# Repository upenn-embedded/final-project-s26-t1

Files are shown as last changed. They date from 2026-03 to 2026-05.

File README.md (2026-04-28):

Review Assignment Due Date (https://classroom.github.com/a/-Acvnhrq)

# Final Project

**Team Number:** 1

**Team Name:** Virtual Etch-a-Sketch

| Team Member Name | Email Address |
| --- | --- |
| Cameron Shaw | cshaw1@seas.upenn.edu |
| Clayton Hickey | clhickey@seas.upenn.edu |
| Elan Goldman | elangol@seas.upenn.edu  |

**GitHub Repository URL:** https://github.com/upenn-embedded/final-project-s26-t1

**GitHub Pages Website URL:** https://upenn-embedded.github.io/final-project-s26-t1/

## Final Project Proposal

### 1. Abstract

A device with a large tri-color e-ink display and knobs that will behave like an Etch-a-sketch, a mechanical 2D plotter toy that draws lines on its screen. Our project will reimagine the experience of using an etch-a-sketch while keeping the shake to erase functionality and classic 2 knobs for controlling the drawing cursor. The virtual etch-a-sketch will also have USB support, so that the knobs can be used to create drawings in apps like MS Paint or GIMP.

### 2. Motivation

The goal of this project is to expand what an etch-a-sketch can be while also reducing the durability issues that arise from the completely mechanical design of the original. The etch-a-sketch was originally designed to be a toy, while the virtual etch-a-sketch is targeted at artists who want a more consistent experience and more ways to augment the etch-a-sketch medium.

### 3. System Block Diagram

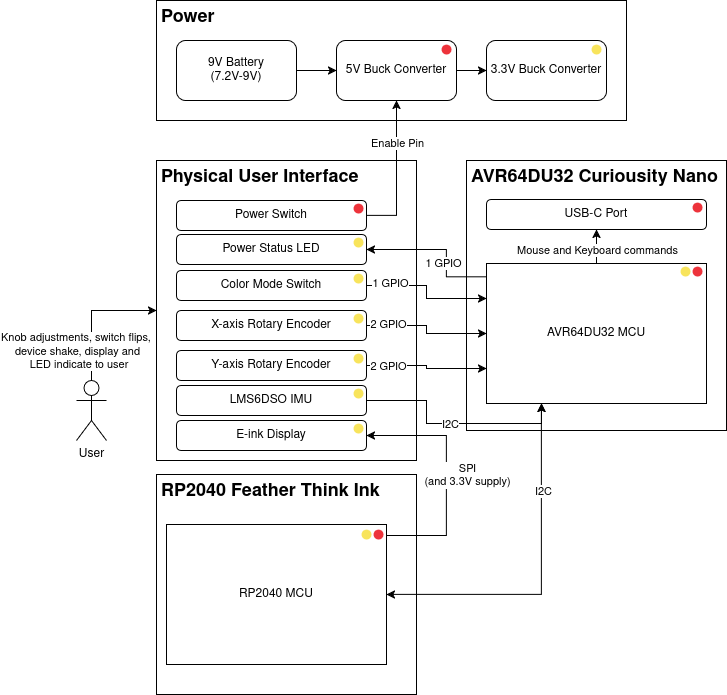
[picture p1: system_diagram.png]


**Key**

Red: Regulated 5V

Yellow: Regulated 3.3V

### 4. Design Sketches

We will 3D print the entire enclosure and knobs for the etch-a-sketch. We will need a soldering iron for making electrical connections, as well as adding heat set inserts if needed.

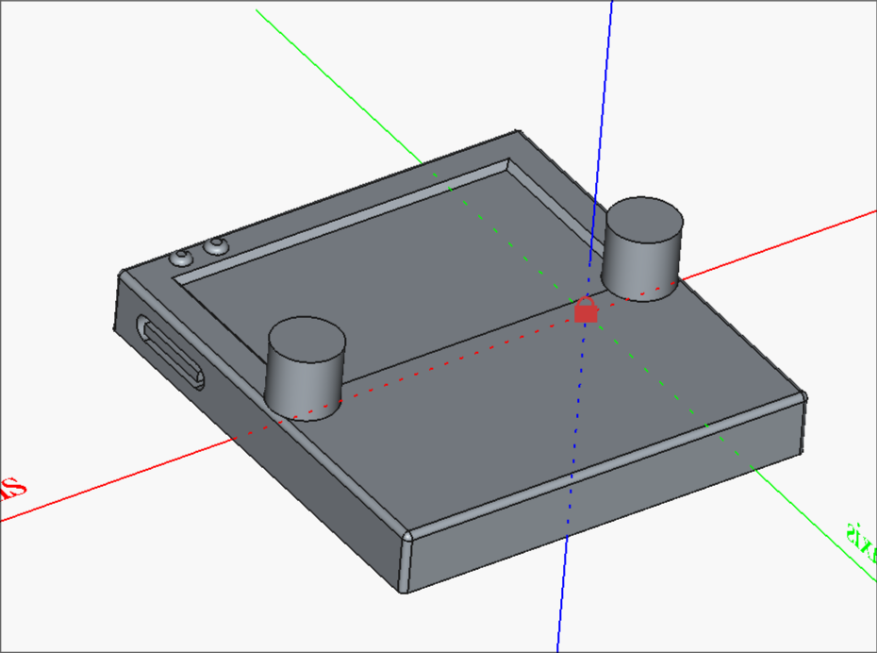
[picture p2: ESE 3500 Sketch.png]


### 5. Software Requirements Specification (SRS)

**5.2 Functionality**

| ID | Description |
| :--- | :--- |
| **SRS-01** | The device shall display and persist user-drawn lines on the display. The cursor shall remain at the boundary of the screen if a user attempts to move it beyond the display coordinates. |
| **SRS-02** | The system shall update the cursor position based on simultaneous inputs from both knobs to do diagonal and curved line rendering. |
| **SRS-03** | The system shall respond to knob rotations with a display latency of less than 100 milliseconds to ensure real-time user interaction. |
| **SRS-04** | Upon USB connection to a host PC, the device shall enumerate as a Human Interface Device (HID) and map knob rotations to mouse-drag and click events. |
| **SRS-05** | The system shall monitor the IMU and trigger a screen-clear event only when a continuous shaking motion is detected for a duration exceeding 1 second. |
| **SRS-06** | The system shall change the active drawing color between black and red upon a toggle of the color mode switch, while maintaining the color of previously drawn lines. |

### 6. Hardware Requirements Specification (HRS)

**6.1 Definitions, Abbreviations**

- **USB:** Universal Serial Bus
- **PC:** Personal Computer
- **HID:** Human Interface Device
- **IMU:** Inertial Measurement Unit

**6.2 Functionality**

| ID | Description |
| :--- | :--- |
| **HRS-01** | The device shall be powered by a 9V Alkaline battery and maintain operation for a minimum of 10 minutes under continuous use. |
| **HRS-02** | The power management circuit shall maintain uninterrupted system operation during the transition of plugging or unplugging a USB-C cable. |
| **HRS-03** | A physical power switch shall be integrated to disconnect the battery from all downstream circuitry, resulting in zero current draw (excluding ambient battery discharge). |
| **HRS-04** | The device enclosure shall feature two knobs positioned at the bottom corners of the display to emulate a mechanical drawing toy. |
| **HRS-05** | The rotary encoders used for knobs shall be non-detented to provide smooth, continuous rotation without tactile clicks or bumps. |
| **HRS-06** | The device chassis and internal component mounting shall withstand shaking without loss of electrical connectivity or functional failure. |

_Note: we used Gemini to format the requirements._

### 7. Bill of Materials (BOM)

https://docs.google.com/spreadsheets/d/18jHvc1XVHpzNt5ybeaLdjjYaHa1GXTPeQhFLGrUgIds/edit?usp=sharing

**AVR64DU32 Curiosity Nano**: This is the main MCU where we will run our bare metal C code. This MCU is responsible for user input, sending drawing commands to the E-Ink MCU, and interfacing with a connected laptop over USB. We chose this board over the Atmega328PB dev board because it has a USB 2.0 interface that we can use to have it act as a keyboard and/or mouse on the connected laptop.
**Rotary Encoder**: We will have two rotary encoders, just as an etch-a-sketch would, one for controlling the x-axis and one for the y-axis. We chose rotary encoders because they allow for many turns in each direction unlike a normal potentiometer and can be read using regular GPIO thanks to their digital output.
**eInk Display**: This is the display of the etch-a-sketch. We chose a large 7.5” display to approximate the dimensions of a full size etch-a-sketch. The eInk display gives the device a look closer to an real etch-a-sketch. The model can also display red pixels, and we will take advantage of this by including a color mode switch.
**IMU Breakout Board**: The IMU will be responsible for detecting when the user shakes the device to clear its screen. We chose this IMU because it is the same as the one used in WS3.
**RP2040 Feather ThinkInk**: This the secondary MCU used to control the eInk display. Because the eInk display requires a full refresh when updating it, we need a separate MCU with enough RAM to store the display state. We chose this board because it is designed for this exact purpose and includes the 24-pin connector that the eInk display uses.
**3.3V/5V Buck Converters**: As shown in the system diagram, we will need 3.3V for most devices on the board, though some require a higher supply voltage for their onboard regulators, hence why we also need a 5V buck converter. The buck converter boards we chose from Sparkfun provide a sufficient amount of current and feature an enable pin that our power switch could use.
**9V Battery Hat + Battery**: We want the device to function wirelessly, so we chose to use a 9V due to the University’s safety requirements. The battery holder will provide 7.2-9V, which is sufficient for the 5V and 3.3V converters.

### 8. Final Demo Goals

The device is battery powered, so it’s sufficient to just have some table space for the device to sit and a connected laptop to demonstrate the additional features of the virtual etch-a-sketch. We should bring an extra battery just in case.

### 9. Sprint Planning

| Milestone  | Functionality Achieved | Distribution of Work |
| --- | --- | --- |
| Sprint #1  | The display turns on and can be drawn to. The USB HID on the Curiousity Nano functions on its own. A preliminary version of the enclosure has been designed. | We will split this work based on our availabilities by meeting before the sprint start. |
| Sprint #2  | The display can be drawn to by the knobs, though some functionality or latency issues may be present. The Curiousity Nano USB HID functions as a mouse using control from the knobs separately. A physical enclosure draft has been printed and components have been test fitted. | We will split this work based on our availabilities by meeting before the sprint starts. |
| MVP Demo | We put all the components in the enclosure and the HID and display programs have been merged so they work simulatenously. The color mode and shake detection has also been added at this point. | We will split this work based on our availabilities by meeting before starting this phase. |
| Final Demo | We satisfy all our required system requirements. | We will split this work based on our availabilities by meeting before starting this phase. |

**This is the end of the Project Proposal section. The remaining sections will be filled out based on the milestone schedule.**

## Sprint Review #1

### Last week's progress

- Ordered parts from Mouser and Amazon as well as the eInk display from Crowd Supply.
- Wrote code for and successfully tested a simple etch-a-sketch using Lab 4 parts. We don't plan on using the Lab 4 display due to its small size or the joystick for it, but this gives us a starting point while we wait for parts to arrive.
- Set up AVR64DU32 in MPLAB X IDE. We have tested USB HID functionality using Microchip's demo.
- Wrote a simple program using Microchip Code Configurator for the AVR64DU32 to test I2C communication with the IMU.
- Acquired a Raspberry Pi 4B with 6" touchscreen display from Detkin staff.
- Set up reproducible RPI image using NixOS. It boots but the screen doesn't work yet.

### Current state of project

- Etch-a-sketch proof of concept using Lab 4 joystick and display
- Working USB HID and I2C on the AVR64DU32 Curiousity Nano
- RPI for driving display is working but only insofar as it boots

### Next week's plan

- Port proof of concept from ATMega328PB to AVR64DU32
- Add shake detection using IMU with AVR64DU32
- Get RPI image working with display
- Replace joystick with rotary encoder dials (assuming they arrive before the end of the week)

## Sprint Review #2

### Last week's progress

- Wrote I2C driver (instead of using MCC generated one) with non-blocking read/write transactions
- USB HID with keyboard and mouse (previously was just keyboard) on AVR64DU32
- Determined we can use Wake Up event on LSM6DSO IMU for shake detection
- Designed draft enclosure in SolidWorks
- Got display on Raspberry Pi working
- Wrapped Niri config for display server testing on Raspberry Pi and normal system
- PR to get [eww](https://github.com/BirdeeHub/nix-wrapper-modules/pull/420) wrapper module
- Wrote plan for Raspberry Pi dash
- Wrote, wrapped, and lightly styled eww config for vendor-like dashboard on Raspberry Pi
- Got virtual keyboard working on Raspberry Pi config
- Got custom drawing program working
- Got custom drawing program partially building for Raspberry Pi

images & videos: [https://github.com/upenn-embedded/final-project-s26-t1/tree/main/sprint2-media](https://github.com/upenn-embedded/final-project-s26-t1/tree/main/sprint2-media)

### Current state of project

- Working mouse and keyboard output from AVR64DU32
- Working communication over I2C with IMU
- 3D model of enclosure
- Raspberry Pi configuration working

### Next week's plan

- Set up rotary encoders to control mouse
- Configure wake up event for IMU and integrate it with USB code
- Test full setup over USB with RPI
- Print enclosure before MVP
- Finish dashboard on RPI and make buttons work

## MVP Demo

We did not make a slide deck

### MVP Requirements

1. Show a system block diagram & explain the hardware implementation.
   1. https://drive.google.com/file/d/1pIQUzEnvfFoCIa2VsQYxRrLAcQYWJmim/view?usp=sharing
   1. AVR Microcontroller
      1. Reads our rotary encoder inputs and translates them to USB HID Mice
      1. Reads our button inputs and interprets them USB HID Keyboard
      1. Reads shaking from the IMU and sends those events through the USB HID Keyboard interface
      1. Sends the USB HID events to our RPI 4B
      1. (unimplemented) 3 LEDs shows power, shaking, and whether left click is held
   1. RPI 4B
      1. Takes the USB HID events
      1. Boots off of custom Etch A Sketch OS image on SD Card
      1. WiFI Connection for debugging
      1. Outputs to the display
1. Explain your firmware implementation, including application logic and critical drivers you've written.
   1. AVR (baremetal C)
      1. Main file is main_usb.c, containing a simple loop for sending I2C commands to IMU and processing USB HID reports.
      2. Timer B is configured to run every ~1ms in CCMP mode. The interrupt for this timer gets the state of the rotary encoders and updates the mouse delta.
      3. Port F (Pin Change) Interrupt is configured for the 4 buttons on both edges (except for the left click hold button which is falling edge).
      4. Created `usb_driver.c`, a USB HID driver with support for sending mouse and keyboard reports on the same endpoint, which is not supported in the MCC library).
         1. Primarily uses the MCC library USBDevice_Handle() and USB_TransferWriteStart() functions.
         2. Supports asynchronous processing of reports: `main_usb.c` can set the next keyboard press or mouse movement but driver will not send until `Process_USB_Reports` is called in the main loop.
      5. Created `i2c_driver.c`, which supports synchronous and asynchronous I2C reads and writes. Commands are specified in a struct that is then updated as it proceeds through the I2C protocol steps.
      6. Created `imu_driver.c`, which is built on top of `i2c_driver.c`.
         1. Contains an Initialize function to configure the Wake-Up Event on the LSM6DSO.
         2. Contains a detect_shake_event() to read from the wake-up interrupt register on the LSM6DSO to see if a wake-up event occurred.
         3. Maintains a counter so that multiple (short) wake-up events occur before a (long) shake event is detected.
   1. RPI 4B
      1. Runs custom "[Etch A Sketch OS](./rpi-install)"
         1. Based on [NixOS](https://nixos.org/)
            1. "Patched" with [nix-hardware](https://github.com/nixos/nixos-hardware) to get the DSI display and GPU working
         1. Everything pre-configured on flashable image for a vendored OS-like experience
            1. Image rebuilt with a single command `nix build .#packages.aarch64-linux.rpi4B-img`, only requiring [Nix](https://nixos.org/download/) to be installed
            1. Build artifact: https://drive.google.com/file/d/1Ibafn8uE3A1nxN8xKzGDzw4241MuhPFP/view?usp=sharing
         1. Logs in to AirPennNet-Device WiFi automatically
         1. Registers itself as `etch-a-sketch.local` on mDNS, DNS-SD, and Bonjour to avoid problems with dynamic IP addressing
         1. OpenSSH enabled for remote development without re-flashing
         1. Uses [Nix Wrapper Modules](https://github.com/BirdeeHub/nix-wrapper-modules) to make OS elements portable between systems (allows rapid testing on development machine)
         1. Uses customized [Niri](https://github.com/niri-wm/niri) as a lightweight display
            1. Pinned to a specific commit to get on-screen keyboard support, avoiding its [temporary removal](https://github.com/nixos/nixos-hardware) (and it was never part of an official release)
            1. Interprets and acts on hotkeys
               1. `Super+Enter`: open terminal
               1. `Super+Q`: exit current app
               1. `Super+K`: toggle on-screen keyboard
               1. `Super+F`: toggle current app fullscreen
         1. Uses customized [Eww](https://github.com/elkowar/eww) to make the vendor-like dashboard
            1. Required [PR](https://github.com/BirdeeHub/nix-wrapper-modules/pull/420) to be able to wrap it to make the configuration portable (runs on development machine as well)
            1. Custom icons
         1. Uses custmized [Yaru](https://github.com/ubuntu/yaru) theme to make the cursor mimic a real Etch A Sketch cursor
         1. Uses [wvkbd](https://github.com/jjsullivan5196/wvkbd) for on-screen keyboard
            1. Required cherry-picking from unstable branch of [nixpkgs](https://github.com/nixos/nixpkgs) to get the version that works with Wayland
      1. Runs custom [Etch](./etch) drawing program for a minimal Etch A Sketch-like experience
         1. Programmed in [Rust](https://rust-lang.org/)
         1. Uses [Egui/Eframe](https://github.com/emilk/egui), a native GUI framework
            1. It's dependency, WGPU, had to be [forked](https://github.com/clay53/wgpu) to fix bug causing it to [fail on Raspberry Pi](https://github.com/gfx-rs/wgpu/issues/9293) and set the version Egui expects
            1. It had to be [forked](https://github.com/clay53/egui) to make it compatible with the in-development branch of WGPU
         1. Always draws following the mouse
         1. Erases with `Ctrl+Z` (sent when IMU detects shaking)
1. Demo your device.
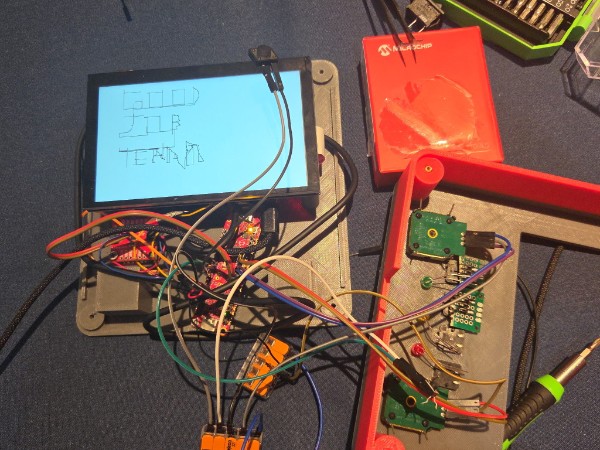
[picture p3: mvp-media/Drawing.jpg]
   1. 
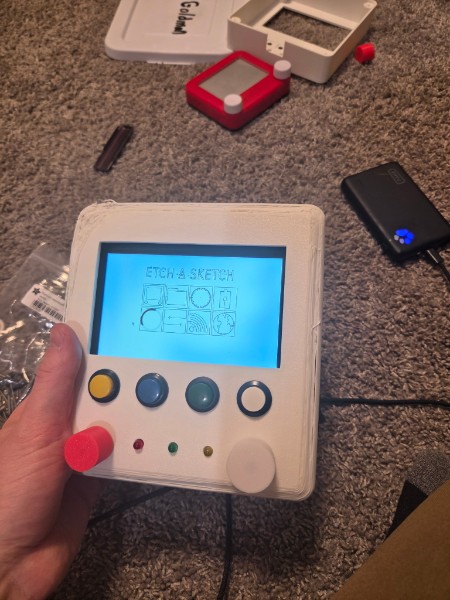
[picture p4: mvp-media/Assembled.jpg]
   1. 
1. Have you achieved some or all of your Software Requirements Specification (SRS)?
   - [x] SRS-01
   - [x] SRS-02
   - [x] SRS-03
   - [x] SRS-04
   - [ ] SRS-05
     - Still need to make it so shake detection is over 1 second
   - [ ] SRS-06
     - This software requirement has been abandoned in favor of a black/white screen
1. Show how you collected data and the outcomes.
   1. All of these are qualitative, so we just tested it: [./mvp-media](/mvp-media/)
1. Have you achieved some or all of your Hardware Requirements Specification (HRS)?
   - [x] HRS-01
     - Lasts a long time with our USB battery pack
   - [x] HRS-02
   - [x] HRS-03
   - [x] HRS-04
   - [x] HRS-05
   - [ ] HRS-06
     - Wires not connected strongly yet
1. Show how you collected data and the outcomes.
   1. For the battery pack lifespan, we ran it for like an hour waiting to demo and it barely went down
   1. Everything else is qualitative and we know by looking at it/shaking it
1. Show off the remaining elements that will make your project whole: mechanical casework, supporting graphical user interface (GUI), web portal, etc.
   1. Everything fits nicely in the case
1. What is the riskiest part remaining of your project?
   1. The riskiest part is whether or not the E-Ink display arrives in time.
1. How do you plan to de-risk this?
   1. It probably won't arrive, so we will design our final enclosure around the LCD we've been using as a backup
1. What questions or help do you need from the teaching team?
   1. None

### What to do before final demo

- Polish OS
  - Implement hands of the clock
  - Implement showing stength of WiFI signal
  - Implement text for storage usage
  - Implement file syncing (probably with WebDAV)
  - Create custom wvkbd layout that makes more sense for our application
- Polish drawing app
  - Each "erase" should erase the image gradually, lightening it, instead of completely erasing it like a real etch a sketch
  - Automatic saves and reloads
- Finalize and stengthen enclosure
  - Need better method to route USB cabels - probably buying a right angle connector
  - Need everything to fit
  - Make knobs grippier
  - Attach internal wires more securely
- Finish AVR I/O
  - Implement LEDs
  - Implement other 2 buttons

## Final Demo

Updates since MVP:

- IMU sensitivity adjusted
- Clock in Etch a Sketch OS
- Saving/loading drawings to local filesystem supported now
- New case and improved wiring
- Added left click hold button, quit/open button, and indicator LEDs

## Final Report

Don't forget to make the GitHub pages public website!
If you’ve never made a GitHub pages website before, you can follow this webpage (though, substitute your final project repository for the GitHub username one in the quickstart guide): [https://docs.github.com/en/pages/quickstart](https://docs.github.com/en/pages/quickstart)

### 1. Video

See website or media folder for demo video.

### 2. Images

See website or media folder for images.

### 3. Results

#### 3.1 Software Requirements Specification (SRS) Results

| ID | Description | Validation Outcome |
| :--- | :--- | --- |
| **SRS-01** | The device shall display and persist user-drawn lines on the display. The cursor shall remain at the boundary of the screen if a user attempts to move it beyond the display coordinates. | Validated, see demonstration video for evidence of this. |
| **SRS-02** | The system shall update the cursor position based on simultaneous inputs from both knobs to do diagonal and curved line rendering. | Validated, see demonstration video for evidence of this. |
| **SRS-03** | The system shall respond to knob rotations with a display latency of less than 100 milliseconds to ensure real-time user interaction. | Confirmed, see demonstration video for anecdotal evidence. |
| **SRS-04** | Upon USB connection to a host PC, such as the MCU for the display, the device shall enumerate as a Human Interface Device (HID) and map knob rotations to mouse-drag and click events. | Partially satisfied, AVR is connected to Raspberry Pi host PC as a HID. See main demonstration video as evidence and photos of inside of case showing USB connection. |
| **SRS-05** | The system shall monitor the IMU and trigger a screen-clear event only when a continuous shaking motion is detected for a duration exceeding 1 second. | Validated, see demonstration video of this behavior. |
| **SRS-06** | The device shall indicate using separate LEDs whether the device is powered, whether left click hold is enabled, and whether shaking is detected. | Validated, see main video for proof that each of these functions is present. |

#### 3.2 Hardware Requirements Specification (HRS) Results

| ID | Description | Validation Outcome |
| :--- | :--- | --- |
| **HRS-01** | The device shall be powered by a USB power bank and maintain operation for a minimum of 10 minutes under continuous use. | Confirmed, device operated for greater than 10 minutes during the final demo. |
| **HRS-02** | The power management circuit shall maintain uninterrupted system operation during the transition of plugging or unplugging a USB-C cable. | Not applicable since USB is not exposed for external computer connection. |
| **HRS-03** | A physical power switch shall be integrated to disconnect the battery from all downstream circuitry, resulting in zero current draw (excluding ambient battery discharge). | Confirmed, switch is wired to be between main USB-C power port and Raspberry Pi as shown in photos. |
| **HRS-04** | The device enclosure shall feature two knobs positioned at the bottom corners of the display to emulate a mechanical drawing toy. | Validated, see photos of device and validation video. |
| **HRS-05** | The rotary encoders used for knobs shall be non-detented to provide smooth, continuous rotation without tactile clicks or bumps. | Validated by physically rotating the knobs and observing no noticeable clicks. Furthermore, the Bourns rotary encoders we used do not have detents. |
| **HRS-06** | The device chassis and internal component mounting shall withstand shaking without loss of electrical connectivity or functional failure. | Validated, see demonstration that device continues to function after shaking in the main video. |

### 4. Conclusion

#### What did you learn from it?

We learned a great deal about USB and the complexities of building a device that uses this protocol instead of a simpler protocol like I2C. The desire to use USB informed many of our design decisions, and we had to understand the report structure for USB human interface devices to successfully communicate.

#### What went well?

Our planning for unforeseen circumstances such as the e-ink display not arriving before the deadline provided to be quite useful, since this did unfortunately end up occuring. Because we had been careful to acquire an alternative 6" TFT display to be driven by the Raspberry Pi, we were able to present a polished project at the final demo.

#### What accomplishments are you proud of?

We are proud of the custom Etch-a-Sketch OS, since its functionality goes far beyond or original expectations/goals for the project. The OS supports browsing websites, which can be useful for playing drawing games such as Skribbl.io, Wi-Fi configuration, file storage, and even a clock in the main menu. This is a very special part of the project for us, and we are quite proud of it.

#### Did you have to change your approach?

We originally planned to use an e-ink diplay due to its ability to replicate the same look and feel as an original Etch-a-Sketch. We realized early on in the project, however, that the refresh rate would be greater than 3Hz for many displays, making the design unfeasable for us. This changed, however, when we discoverd the Modos 7" Dev Kit, which has a refresh rate of up to 75Hz. We were not able to obtain the display in time, but our backup plan with a 6" TFT display was already in place when this became apparent.

#### What could have been done differently?

We could have used I2C to communicate between the Raspberry Pi and AVR to allow for additional connectivity via USB to a host PC. The primary reason us not going this route was to avoid time cost and redundancy.. in retrospect, using I2C between the RPI and AVR would have been straightforward to switch to, but certainly easier if this decision was made earlier on in the process.

#### What could be the next step for this project?

We would like to improve the device mainly in its hardware by swapping the TFT display to a high-refresh rate e-ink display. We would also like to improve the wiring in some parts of the device. Lastly, we could improve the usability of the OS, prioritizing the 4 buttons and 2 knobs we are able to reprogram.

## References

- [TI I2C Application Report](https://www.ti.com/lit/an/slva704/slva704.pdf)
- [MCC library for UART](https://onlinedocs.microchip.com/oxy/GUID-5A03F818-B7FC-4062-9792-57D08543B586-en-US-11/index.html) (used for debugging purposes only)
- [Microchip USB HID Communication Demo Code](https://github.com/microchip-pic-avr-examples/avr64du32-cnano-usb-hid-keyboard-mplab-mcc)
  - We used this demo code to understand how the MCC library for USB HID works. At a high level, the library creates multiple abstraction layers for the USB interface, handling device descriptors, read/write transfers, and the USB report structure. The library performs the initial handshake with the host to identify itself as a mouse/keyboard HID. USB peripherals like the one we created work by responding to requests from the host with a report containing the keys that are currently pressed and any mouse movements. The original MCC generated code does not support mouse and keyboard simultaneously, so we added support for this by updating `usb/usb_descriptors.c` to include a larger report with separate mouse and keyboard collections. The `usb_driver.c` we wrote then uses `USB_TransferWriteStart()` to send mouse or keyboard reports, alternating between the two.

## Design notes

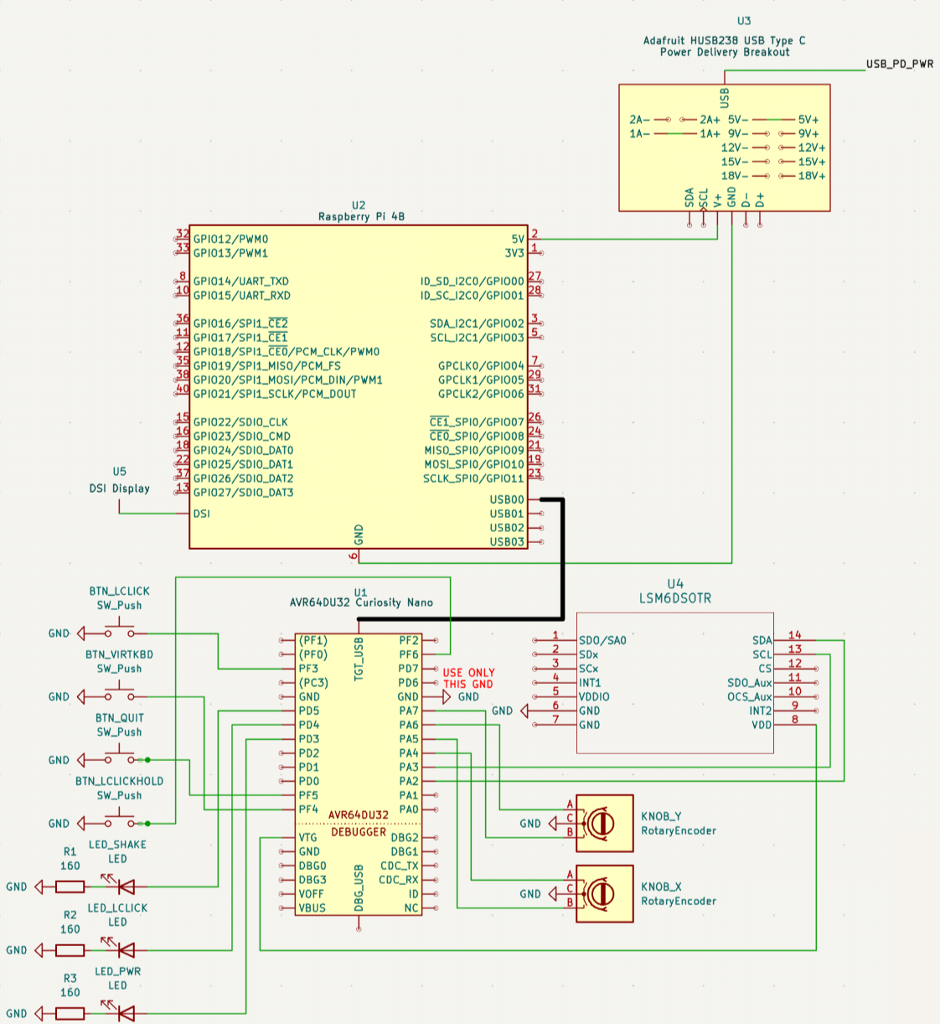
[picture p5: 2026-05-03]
website-media/schematic.png

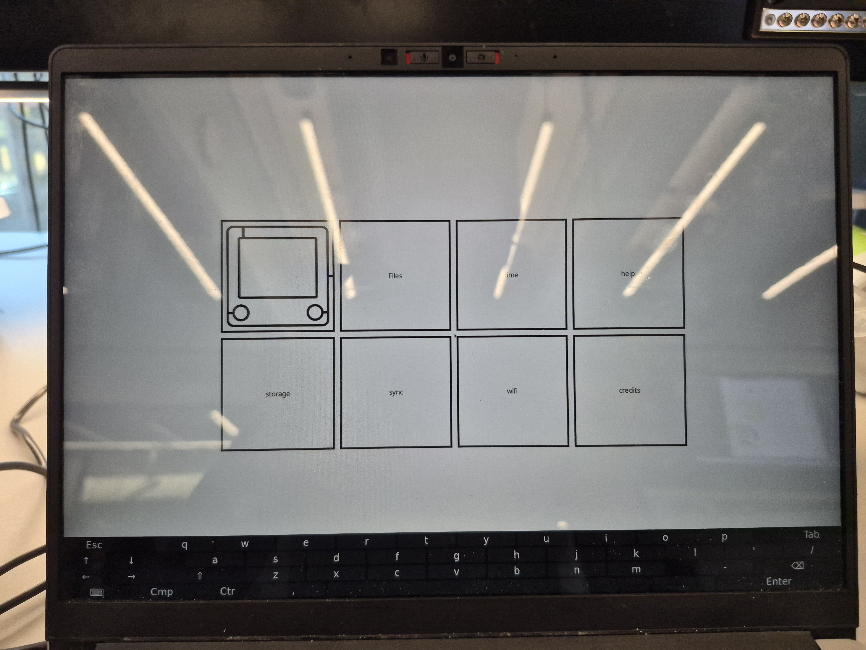
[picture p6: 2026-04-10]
sprint2-media/virtual keyboard.jpg

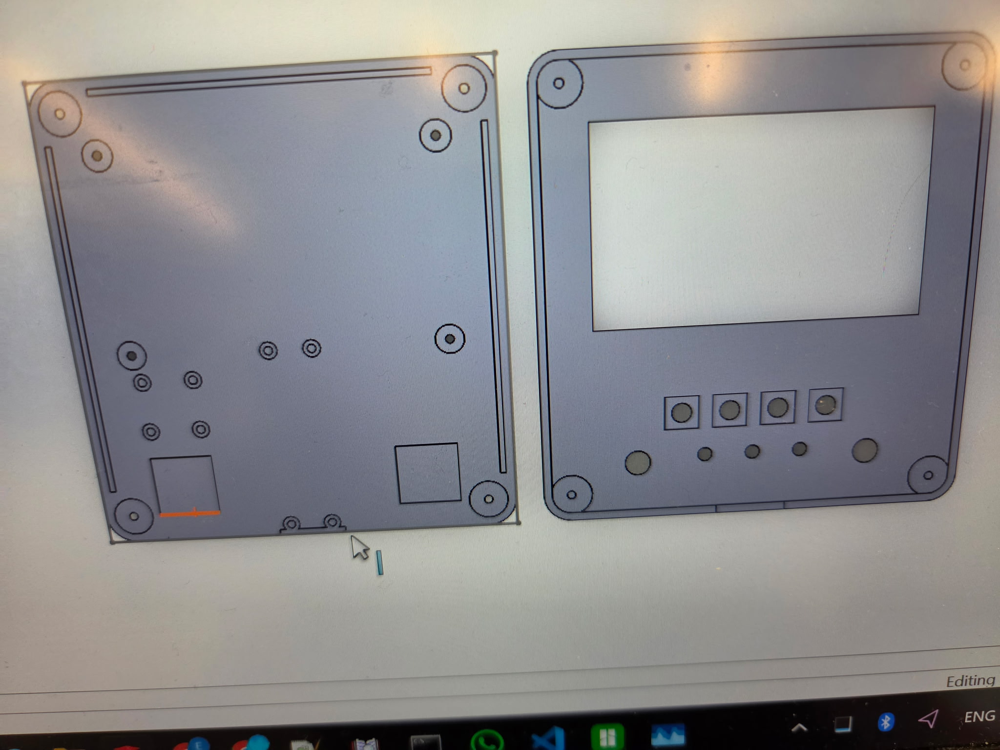
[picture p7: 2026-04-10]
sprint2-media/Enclosure2.jpg

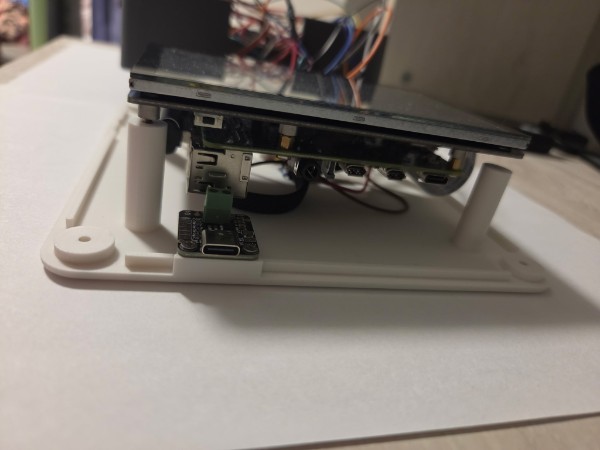
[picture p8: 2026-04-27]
website-media/internals-power.jpeg

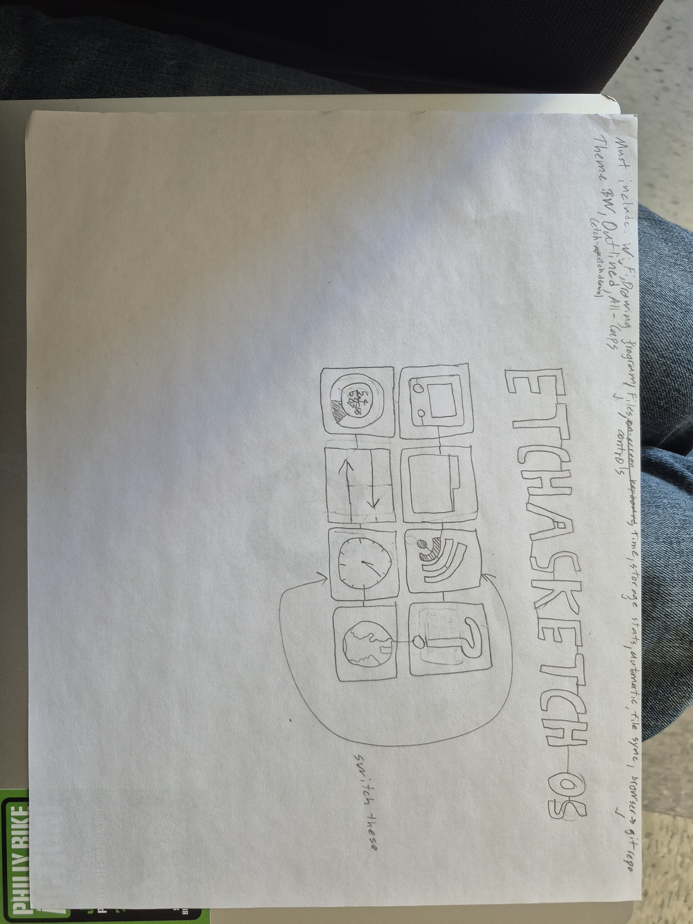
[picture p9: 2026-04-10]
sprint2-media/dashboard plan.jpg

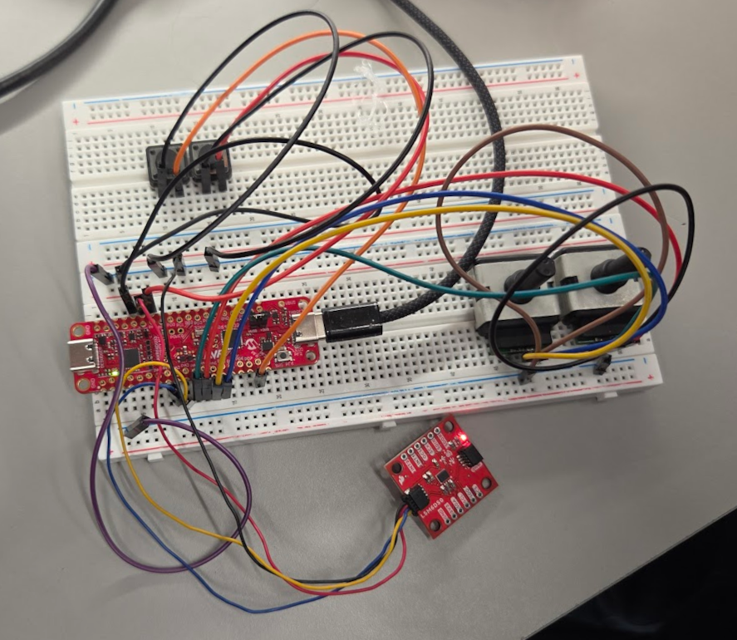
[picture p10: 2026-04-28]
website-media/avr-dev.png

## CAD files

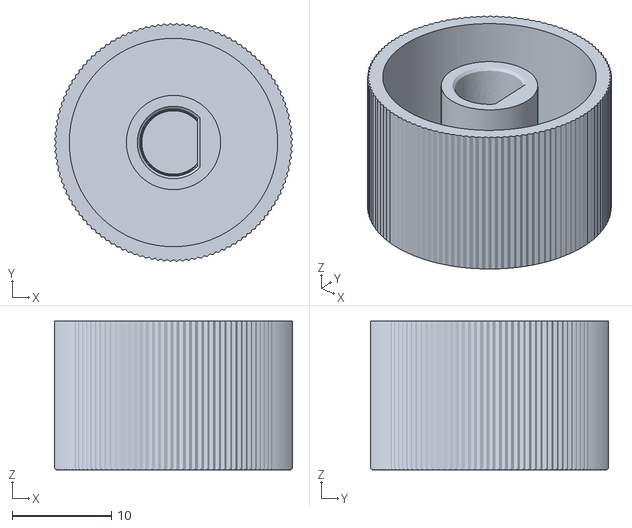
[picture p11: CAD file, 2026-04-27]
enclosure/knob.stl
24.0 x 24.0 x 15.0

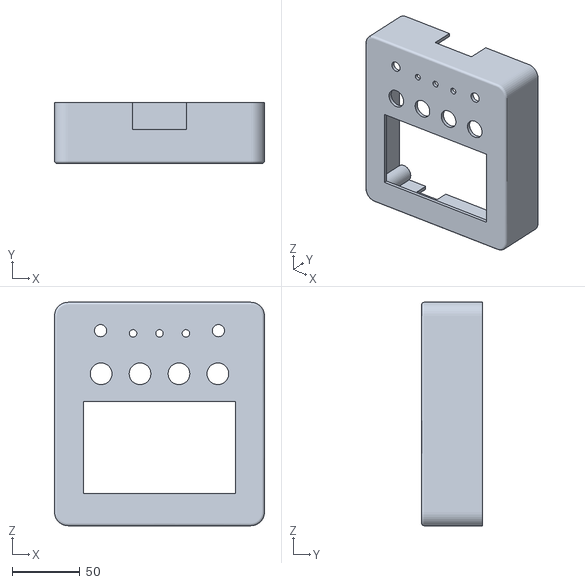
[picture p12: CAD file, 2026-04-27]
enclosure/top.stl
155.0 x 45.0 x 165.0

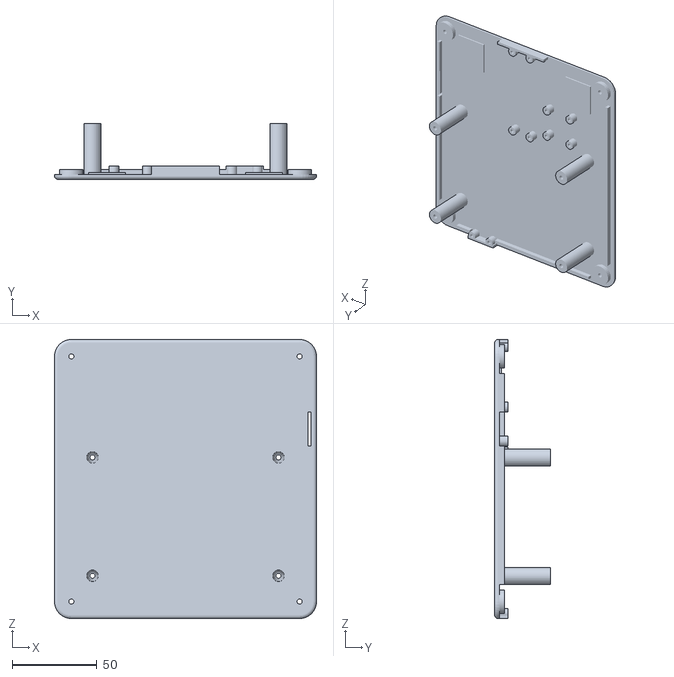
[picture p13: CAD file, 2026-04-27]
enclosure/bottom.stl
155.0 x 33.0 x 165.0

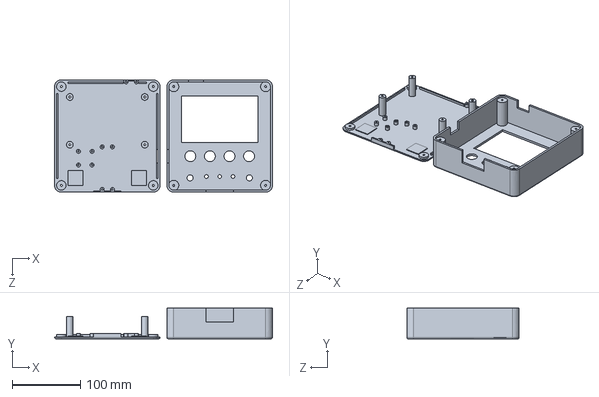
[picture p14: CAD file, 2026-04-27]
enclosure/etchV4.SLDPRT
320.0 x 45.0 x 165.0 mm

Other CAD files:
assets/wifi.FCStd

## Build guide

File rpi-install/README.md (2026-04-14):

This is the code we use to create the image to flash onto the Raspberry Pi Model 4 B

# Plan
Use NixOS to create a reproducible image

# Installation Instructions
1. Clone this repository: `git clone https://github.com/upenn-embedded/final-project-s26-t1.git`
2. cd into the repository: `cd final-project-s26-t1`
3. ensure you have [nix](https://nixos.org/download/) installed
4. build the image: `nix build .#packages.aarch64-linux.rpi4B-img` (you may have to enable cross-compiling for `aarch64-linux` - I'm on NixOS with cross compilation enabled in my system config, so it just works for me)
5. plug-in the SD card into your system
6. Figure out which `disk` you need to flash (BE CAREFUL): `lsblk`
```
NAME                                          MAJ:MIN RM   SIZE RO TYPE  MOUNTPOINTS
sda                                             8:0    1  58.3G  0 disk
├─sda1                                          8:1    1   512M  0 part
└─sda2                                          8:2    1  57.8G  0 part
nvme0n1                                       259:0    0 931.5G  0 disk
├─nvme0n1p1                                   259:1    0 443.6G  0 part
│ └─luks-c705edf8-6321-4956-8780-f6c00a62e77e 254:0    0 443.6G  0 crypt /home
├─nvme0n1p5                                   259:2    0  96.8G  0 part
├─nvme0n1p6                                   259:3    0   512M  0 part  /boot
└─nvme0n1p7                                   259:4    0 390.6G  0 part  /nix/store`
```
7. In my case, the disk I need to flash is `sda`, which I can tell based off the size (64GB microSD card)
8. flash the SD card: `sudo dd if=result/sd-image/$(ls result/sd-image/) of=/dev/sdX bs=4M status=progress oflag=direct` (replace `sdX` with the drive you determined you need to flash). BE CAREFUL TO NOT OVERWRITE ANYTHING YOU WANT TO KEEP
9. put the SD card back into the Raspberry Pi

# Post-Install State
 * Automatically connects to AirPennNet-Device (you will have to register your device's MAC address to get it authorized to the network - you can find you mac address with `ip link` and look for the one associated with `wlan0`)
 * Automatically logs into all TTYs as `root`
 * `root` password is secret, but is already pre-set
 * OpenSSH open on all network interfaces with password login into `root`
 * Some utility packages pre-installed like `htop`, `neovim`, and `fastfetch`
 * Publishes itself to the local network through `avahi` (which you may also have to install) as `etch-a-sketch.local`

# Development Tips
* **connect via ssh**: `ssh root@etch-a-sketch.local`
* **"remember" etch-a-sketch password**: `ssh-copy-id root@etch-a-sketch.local`
* **update configuration remotely without re-flashing**
    * NixOS Machines: `nixos-rebuild switch --flake .#etch-a-sketch --target-host root@etch-a-sketch.local`
        * It can sometimes be faster to also build on the Pi so you don't have to cross-compile: `nixos-rebuild switch --flake .#etch-a-sketch --target-host root@etch-a-sketch.local --build-host root@etch-a-sketch.local`
    * idk: https://github.com/NixOS/nixpkgs/issues/44135
* **test desktop configuration locally** (Wayland only): `nix run .#niri-wrapped` (nicer if go to different TTY: `Ctrl+Alt+F#`)

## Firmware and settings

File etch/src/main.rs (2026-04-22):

use std::{fs::{self, File, OpenOptions}, io::{BufReader, BufWriter, Read, Seek, SeekFrom, Write}, sync::Arc};

use bytemuck::cast_slice;
use eframe::{egui::{self, Color32, ColorImage, Key, Pos2, ViewportCommand}, egui_wgpu::{WgpuConfiguration, WgpuSetup, WgpuSetupCreateNew}, wgpu::{self, Features}};
use serde::{Deserialize, Serialize};

fn main() -> eframe::Result {
    // force limits lower for raspberry pi
    let mut wgpu_setup_create_new = WgpuSetupCreateNew::without_display_handle();
    wgpu_setup_create_new.device_descriptor = Arc::new(|_adapter| {
        let base_limits = wgpu::Limits::downlevel_webgl2_defaults();

        wgpu::DeviceDescriptor {
            label: Some("egui wgpu device"),
            required_features: Features::empty(),
            required_limits: wgpu::Limits {
                max_texture_dimension_2d: 3840, // slightly larger for laptop display
                ..base_limits
            },
            ..Default::default()
        }
    });

    let native_options = eframe::NativeOptions {
        viewport: egui::ViewportBuilder::default()
            .with_fullscreen(true),
        wgpu_options: WgpuConfiguration {
            wgpu_setup: WgpuSetup::CreateNew(wgpu_setup_create_new),
            ..Default::default()
        },
        ..Default::default()
    };
    eframe::run_native(
        "Etch",
        native_options,
        Box::new(|cc| Ok(Box::new(App::new(cc))))
    )
}

struct App {
    frame_counter: usize,
    image: Option<ColorImage>,
    texture: Option<egui::TextureHandle>,
    cursor_texture: Option<egui::TextureHandle>,
    last_cursor_pos: Pos2,
    blank: bool,
    file_set: Option<FileSet>,
}

impl App {
    fn new(cc: &eframe::CreationContext) -> Self {
        egui_extras::install_image_loaders(&cc.egui_ctx);
        Self {
            image: None,
            frame_counter: 0,
            texture: None,
            cursor_texture: None,
            last_cursor_pos: Pos2::ZERO,
            blank: true,
            file_set: None,
        }
    }
}

impl eframe::App for App {
    fn ui(&mut self, ui: &mut egui::Ui, _frame: &mut eframe::Frame) {
        if self.texture.is_none() {
            // TODO: find a less dumb way to do this
            if self.frame_counter < 3 { // wait until monitor size propagates
                self.frame_counter += 1;
                // make sure monitor scaling factor is ignored
                ui.ctx().set_pixels_per_point(1.0);
                return;
            } else {
                let size = ui.ctx().viewport_rect().size();
                let scale = ui.ctx().pixels_per_point();

                assert!(scale == 1.0, "Scale should be 1");
                println!("got monitor size of {}", size);

                ui.send_viewport_cmd(ViewportCommand::CursorGrab(egui::CursorGrab::Locked));
                ui.send_viewport_cmd(ViewportCommand::CursorVisible(false));

                if let Some(mut file_set) = FileSet::get(size.x as usize, size.y as usize) {
                    self.image = Some(ColorImage::new(
                        [
                            size.x as usize,
                            size.y as usize,
                        ],
                        file_set.pixels(),
                    ));

                    let [cursor_x, cursor_y] = file_set.cursor_pos();
                    self.last_cursor_pos = Pos2::new(cursor_x, cursor_y);

                    self.file_set = Some(file_set);
                } else {
                    self.image = Some(ColorImage::filled([size.x as usize, size.y as usize], Color32::WHITE));

                    self.last_cursor_pos = Pos2::new(size.x/2.0, size.y/2.0);

                    self.file_set = Some(FileSet::new(self.image.as_ref().unwrap(), self.last_cursor_pos.x, self.last_cursor_pos.y));
                }
            }
        }

        let image = self.image.as_mut().expect("image should be here");

        let texture_handle = self.texture.get_or_insert_with(|| {
            ui.ctx().load_texture(
                "my-image",
                image.clone(),
                Default::default()
            )
        });

        if
            let Some(motion) = ui.input(|i| i.pointer.motion())
        {
            let cursor_pos = (self.last_cursor_pos + motion*2.66)
                .clamp(Pos2::ZERO, Pos2::new(image.width() as f32, image.height() as f32));

            let buffer = 1;
            let rect_x1: usize = usize::saturating_sub(
                self.last_cursor_pos.x.min(cursor_pos.x) as usize,
                buffer
            );
            let rect_x2: usize = usize::min(
                image.width()-1,
                self.last_cursor_pos.x.max(cursor_pos.x) as usize + buffer,
            );
            let rect_y1: usize = usize::saturating_sub(
                self.last_cursor_pos.y.min(cursor_pos.y) as usize,
                buffer
            );
            let rect_y2: usize = usize::min(
                image.height()-1,
                self.last_cursor_pos.y.max(cursor_pos.y) as usize + buffer,
            );

            for x in rect_x1..=rect_x2 {
                let xf = x as f32;
                for y in rect_y1..=rect_y2 {
                    let yf = y as f32;
                    let dist_from_line =
                        (
                            (cursor_pos.y-self.last_cursor_pos.y)*xf
                            -(cursor_pos.x-self.last_cursor_pos.x)*yf
                            +cursor_pos.x*self.last_cursor_pos.y
                            -cursor_pos.y*self.last_cursor_pos.x
                        ).abs()
                        /(
                            (cursor_pos.y-self.last_cursor_pos.y)*(cursor_pos.y-self.last_cursor_pos.y)
                            +(cursor_pos.x-self.last_cursor_pos.x)*(cursor_pos.x-self.last_cursor_pos.x)
                        ).sqrt();
                    if dist_from_line < 1.0 {
                        let index = image.width()*y+x;
                        image.pixels[index] = Color32::BLACK;
                    }
                }
            }

            self.last_cursor_pos = cursor_pos;
            self.blank = false;
            texture_handle.set(image.clone(), Default::default());
        }

        if ui.input(|i| i.modifiers.ctrl && i.key_pressed(Key::Z)) {
            let cursor_pos = self.last_cursor_pos;
            if let Some(file_set) = self.file_set.as_mut() {
                file_set.save(image, cursor_pos.x, cursor_pos.y);
            }
            
            *image = ColorImage::filled([image.width(), image.height()], Color32::WHITE);
            texture_handle.set(image.clone(), Default::default());

            self.file_set = Some(FileSet::new(image, cursor_pos.x, cursor_pos.y));
        }

        ui.image(egui::load::SizedTexture::from_handle(texture_handle));
        const CURSOR_SIZE: f32 = 7.0;
        egui::Image::new(egui::include_image!("../cursor.svg"))
            .paint_at(ui, egui::Rect {
                min: Pos2::new(self.last_cursor_pos.x-CURSOR_SIZE/2.0, self.last_cursor_pos.y-CURSOR_SIZE/2.0),
                max: Pos2::new(self.last_cursor_pos.x+CURSOR_SIZE/2.0, self.last_cursor_pos.y+CURSOR_SIZE/2.0)
            });
    }

    fn on_exit(&mut self) {
        if
            let Some(mut file_set) = self.file_set.take()
            && let Some(image) = self.image.as_ref()
        {
            file_set.save(image, self.last_cursor_pos.x, self.last_cursor_pos.y);
            println!("Saved before exit!");
            drop(file_set);
        }
    }
}

#[derive(Serialize, Deserialize)]
struct Metadata {
    version: usize,
    cursor_x: f32,
    cursor_y: f32,
}

impl Metadata {
    fn new(cursor_x: f32, cursor_y: f32) -> Self {
        Self {
            version: 1,
            cursor_x,
            cursor_y,
        }
    }

    fn to_json(&self) -> String {
        serde_json::to_string(self).expect("Failed to convert metadata to string")
    }
}

struct FileSet {
    image: File,
    metadata: File,
}

impl FileSet {
    fn new(initial_image: &ColorImage, cursor_x: f32, cursor_y: f32) -> FileSet {
        let mut path = dirs::picture_dir().expect("Must have a pictures directory");
        assert!(path.is_dir(), "Pictures dir must exist");

        path.push("Etches");
        if !path.is_dir() {
            fs::create_dir(&path).expect("Failed to make Etches directory");
        }

        path.push(format!("{}x{}", initial_image.width(), initial_image.height()));
        if !path.is_dir() {
            fs::create_dir(&path).expect("Failed to make directory for resolution");
        }

        let filename = chrono::Local::now().format("%+").to_string();
        path.push(&filename);

        let mut metadata_path = path.clone();
        metadata_path.add_extension("json");

        let image_path = { path.add_extension("png"); path };

        assert!(!metadata_path.exists(), "What to do if metadata file already exists not done");
        assert!(!image_path.exists(), "What to do if image file already exists not done");

        let image = fs::File::create_new(image_path).expect("Failed to create image file");

        let metadata = fs::File::create_new(metadata_path).expect("Failed to create metadata file");
        
        let mut file_set = FileSet {
            image,
            metadata,
        };

        file_set.save(initial_image, cursor_x, cursor_y);

        file_set
    }

    fn get(width: usize, height: usize) -> Option<FileSet> {
        let Some(mut path) = dirs::picture_dir() else { return None };

        path.extend(["Etches", format!("{}x{}", width, height).as_str()]);

        let Ok(read_dir) = path.read_dir() else { return None };

        let mut filename = String::new();
        let mut image: Option<File> = None;
        let mut metadata: Option<File> = None;

        for file in read_dir {
            let Ok(dirent) = file else { continue };

            let Some(Some(stem)) = dirent.path().file_stem().map(|s| s.to_str().map(|s| s.to_string())) else { continue };

            if stem > filename || filename.is_empty() {
                filename.clear();
                filename.push_str(&stem);
                image = None;
                metadata = None;
            }

            if stem == filename {
                match dirent.path().extension().map(|s| s.to_str()) {
                    Some(Some("png")) => if let Ok(opened_image) = OpenOptions::new().read(true).write(true).open(dirent.path()) {
                        image = Some(opened_image);
                    },
                    Some(Some("json")) => if let Ok(opened_metadata) = OpenOptions::new().read(true).write(true).open(dirent.path()) {
                        metadata = Some(opened_metadata);
                    },
                    _ => {}
                }
            }
        }

        if let Some(image) = image && let Some(metadata) = metadata {
            Some(FileSet {
                image,
                metadata,
            })
        } else {
            None
        }
    }

    fn save(&mut self, image: &ColorImage, cursor_x: f32, cursor_y: f32) {
        self.image.set_len(0).expect("Failed to truncate image");
        self.image.seek(SeekFrom::Start(0)).expect("Failed to seek in image");

        let mut encoder = png::Encoder::new(BufWriter::new(&mut self.image), image.width() as u32, image.height() as u32);
        encoder.set_color(png::ColorType::Rgba);
        encoder.set_depth(png::BitDepth::Eight);
        let mut encoder = encoder.write_header().unwrap();
        encoder.write_image_data(cast_slice(image.pixels.as_slice())).unwrap();
        encoder.finish().unwrap();

        self.metadata.set_len(0).expect("Failed to truncate metadata");
        self.metadata.seek(SeekFrom::Start(0)).expect("Failed to seek in metadata");
        self.metadata.write_all(Metadata::new(cursor_x, cursor_y).to_json().as_bytes()).expect("Failed to write metadata data");
    }

    fn pixels(&mut self) -> Vec<Color32> {
        //self.image.read_to_end(&mut pixels).expect("Failed to read image");
        let decoder = png::Decoder::new(BufReader::new(&mut self.image));
        let mut decoder = decoder.read_info().unwrap();
        let mut pixels = vec![0; decoder.output_buffer_size().unwrap()]; // slower to make new vec, but don't want to do
                                     // crazy casts rn
        decoder.next_frame(&mut pixels).unwrap();

        let pixels = Vec::from(cast_slice(pixels.as_slice()));

        pixels
    }

    fn cursor_pos(&mut self) -> [f32; 2] {
        let mut metadata_string = String::new();
        self.metadata.read_to_string(&mut metadata_string).unwrap();
        let metadata: Metadata = serde_json::from_str(&metadata_string).unwrap();
        [metadata.cursor_x, metadata.cursor_y]
    }
}

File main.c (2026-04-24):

#include "lib/usb_driver.h"
#include "mcc_generated_files/system/system.h"
#include <avr/io.h>
#include <avr/interrupt.h>
#include <util/delay.h>
#include "lib/lsm6dso_driver.h"
#include <stdint.h>
#include <util/atomic.h>

// Port F buttons
#define LCLICK_BM PIN3_bm
#define VIRTKBD_BM PIN4_bm
#define QUIT_BM PIN5_bm
#define LCLICKHOLD_BM PIN6_bm

// Port D LEDs
#define POWER_LED_BM PIN3_bm
#define LCLICK_LED_BM PIN4_bm
#define SHAKE_LED_BM PIN5_bm

static bool lclick_hold_flag = false;

void io_init(void) {
    // Rotary encoders
    // set PA4, PA5, PA6, PA7 as inputs
    PORTA.DIRCLR = PIN4_bm | PIN5_bm | PIN6_bm | PIN7_bm;

    // Enable pullup for all 4 pins
    PORTA.PIN4CTRL = PORT_PULLUPEN_bm; // encoder X - A
    PORTA.PIN5CTRL = PORT_PULLUPEN_bm; // encoder X - B
    PORTA.PIN6CTRL = PORT_PULLUPEN_bm; // encoder Y - A
    PORTA.PIN7CTRL = PORT_PULLUPEN_bm; // encoder Y - B
    
    // Buttons
    PORTF.DIRCLR = LCLICK_BM | VIRTKBD_BM | QUIT_BM | LCLICKHOLD_BM;
    PORTF.PIN3CTRL = PORT_PULLUPEN_bm | PORT_ISC_BOTHEDGES_gc;
    PORTF.PIN4CTRL = PORT_PULLUPEN_bm | PORT_ISC_BOTHEDGES_gc;
    PORTF.PIN5CTRL = PORT_PULLUPEN_bm | PORT_ISC_BOTHEDGES_gc;
    PORTF.PIN6CTRL = PORT_PULLUPEN_bm | PORT_ISC_FALLING_gc;
    
    // Debug LED
    PORTF.DIRSET = PIN2_bm;
    PORTF.OUTCLR = PIN2_bm;
    
    // Enclosure LEDs
    PORTD.DIRSET = POWER_LED_BM | LCLICK_LED_BM | SHAKE_LED_BM;
    PORTD.OUTSET = POWER_LED_BM;
    PORTD.OUTCLR = LCLICK_LED_BM;
    PORTD.OUTCLR = SHAKE_LED_BM;
}

void timer_init(void) {
    TCB0.CCMP = 1200; // set interrupt to every 1ms (12MHz / 1000)
    TCB0.INTCTRL = TCB_CAPT_bm;
    TCB0.CTRLA = TCB_CLKSEL_DIV1_gc | TCB_ENABLE_bm;
}

ISR(TCB0_INT_vect) {
    static uint8_t last_state = 0;
    
    // capture the current state of the last 4 pins of PORTA
    uint8_t current_state = (PORTA.IN >> 4) & 0x0F;

    if (current_state != last_state) {
        // toggle LED for debugging
        PORTF.OUTTGL = PIN2_bm;
        
        // process x axis encoder
        uint8_t curr_x = current_state & 0x03;
        uint8_t last_x = last_state & 0x03;
        
        if (curr_x != last_x) {
            if ((last_x & 0x01) ^ ((curr_x & 0x02) >> 1)) {
                delta_next_mouse_move(1, 0);
            } else {
                delta_next_mouse_move(-1, 0);
            }
        }

        // process y axis encoder
        uint8_t curr_y = (current_state >> 2) & 0x03;
        uint8_t last_y = (last_state >> 2) & 0x03;
        
        if (curr_y != last_y) {
            if ((last_y & 0x01) ^ ((curr_y & 0x02) >> 1)) {
                delta_next_mouse_move(0, 1);
            } else {
                delta_next_mouse_move(0, -1);
            }
        }

        last_state = current_state;
    }
    
    TCB0.INTFLAGS = TCB_CAPT_bm;
}

ISR(PORTF_PORT_vect) {
    uint8_t intflags = PORTF.INTFLAGS;
    if (intflags & LCLICK_BM) {
        if (!lclick_hold_flag) {
            set_left_click((PORTF.IN & LCLICK_BM) == 0);
            PORTF.OUTTGL = PIN2_bm;
        }
        PORTF.INTFLAGS = LCLICK_BM;
    }
    
    if (intflags & LCLICKHOLD_BM) {
        if (!lclick_hold_flag) {
            PORTD.OUTSET = LCLICK_LED_BM;
            set_left_click(true);
        } else {
            PORTD.OUTCLR = LCLICK_LED_BM;
            set_left_click(false);
        }
        lclick_hold_flag = !lclick_hold_flag;
        
        PORTF.OUTTGL = PIN2_bm;
        PORTF.INTFLAGS = LCLICKHOLD_BM;
    }
    
    if (intflags & VIRTKBD_BM) {
        if (!(PORTF.IN & VIRTKBD_BM)) {
            set_keyboard_press(usb_kbd_super_k);
        } else {
            set_keyboard_press(usb_kbd_no_keys);
        }
        PORTF.OUTTGL = PIN2_bm;
        PORTF.INTFLAGS = VIRTKBD_BM;
    }
    
    if (intflags & QUIT_BM) {
        if (!(PORTF.IN & QUIT_BM)) {
            set_keyboard_press(usb_kbd_super_q);
        } else {
            set_keyboard_press(usb_kbd_no_keys);
        }
        PORTF.OUTTGL = PIN2_bm;
        PORTF.INTFLAGS = QUIT_BM;
    }
}

int main(void) {
    // Initialize MCC
    SYSTEM_Initialize();
    
    // Initialize USB
    Initialize_USB();
    
    // Initialize IMU
    Initialize_IMU();
    
    // Initialize I/O and timer for rotary encoders
    io_init();
    timer_init();
    
    sei();
    
    bool release_after_shake_flag = false;
    
    while (1) {
        Process_USB_Reports();
        
        if (release_after_shake_flag) {
            set_keyboard_press(usb_kbd_no_keys);
            release_after_shake_flag = false;
        }
        
        if (detect_shake_event(SHAKE_LED_BM)) {
            PORTF.OUTTGL = PIN2_bm;
            set_keyboard_press(usb_kbd_ctrl_z);
            _delay_ms(50); // simulate 50ms keyboard press
            release_after_shake_flag = true;
        }
    }
    return 0;
}

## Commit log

2026-04-03 Add MCC config and I2C test code
2026-04-08 nix-wrapper-modules PR merged!! 🥳
2026-04-09 Add i2c driver and imu test code
2026-04-09 i2c driver bug fixes
2026-04-10 Add async support to I2C driver
2026-04-10 refactor and add drawing button into gui
2026-04-14 Add USB driver and main_usb.c for demo
2026-04-14 Fix compilation issues in usb driver
2026-04-15 Get IMU wakeup event working
2026-04-15 files button working
2026-04-15 wifi logo
    [wifi.FCStd]
2026-04-15 make commands on buttons optional
2026-04-15 prevent jump on start
    [main.rs]
2026-04-15 prevent jump on start cleaner
    [main.rs]
2026-04-15 pin output hashes? why?
2026-04-15 battery and sync icons
2026-04-15 browser button
2026-04-15 Integrate IMU
2026-04-15 fix buttons
2026-04-17 Add 2 new buttons and switch to port F interrupt
2026-04-21 Add LED indicators
2026-04-24 Modify SRS-06 to reflect changes in LED indications
    Updated SRS-06 to include shaking detection instead of screen clear event.
2026-04-27 switch to static html site
2026-04-27 Enclosure added
    [bottom.stl, etchV4.SLDPRT, top.stl]
2026-04-27 knob stl, finish OS description
    [knob.stl]
2026-05-02 starting wiring
    [wiring.kicad_pcb, wiring.kicad_sch]
2026-05-03 AVR and RPI wired together
    [wiring.kicad_sch]
2026-05-03 completed kicad diagram
    [wiring.kicad_sch]
2026-05-03 missing DSI Display
    [wiring.kicad_sch]
2026-05-03 Add schematic to website
